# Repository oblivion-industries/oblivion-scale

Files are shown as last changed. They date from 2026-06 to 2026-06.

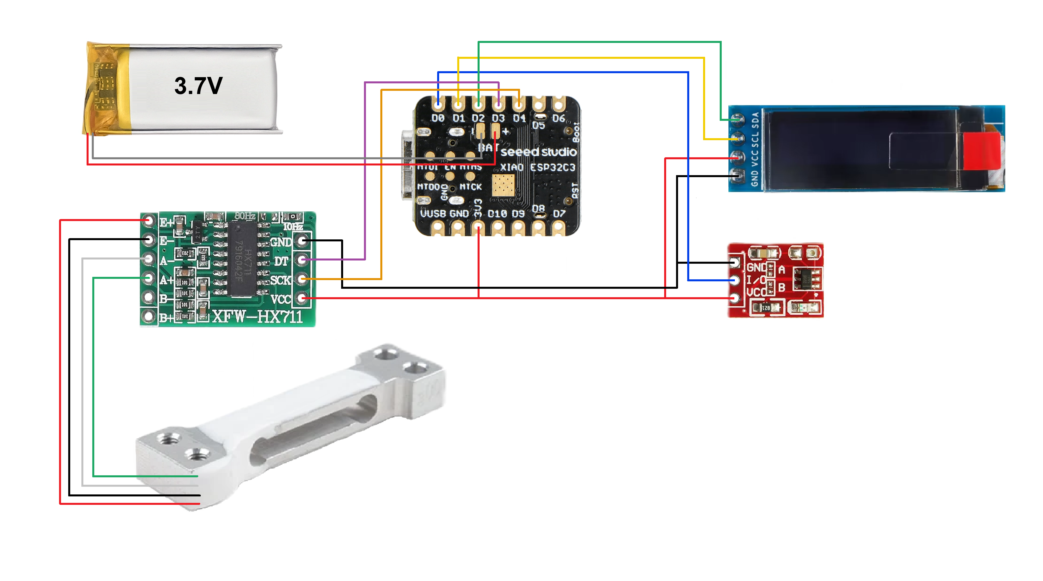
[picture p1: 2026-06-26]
WIRING/v0 wiring diagram.png

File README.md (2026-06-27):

# oblivion-scale

Early **v0 prototype** - open-sourcing the CAD and firmware as a starting point. The rough edges below are exactly where help is welcome.

## Known issues / help wanted

**Body** - v0 is modeled around non-standard parts.
- Re-spec the body around standard, AliExpress-available components.

**Wiring diagram** - v0 is very messy.
- Re-draw the diagram and add a 2-button version.

> [!WARNING]
> Data pins can be changed, but the **wake button** data line **must** be on an **RTC GPIO pin**; otherwise it cannot wake the ESP32 from deep sleep.

**Code** - works, but needs improvement.
- Update for a faster refresh rate.
- Later: add BLE for phone-app compatibility.

## Roadmap

- **Now (v0) - Working prototype:** open-sourcing the body CAD and firmware as a starting point.
- **v1 - Fully open & sourceable:** redesign the body around standard, AliExpress-available parts so anyone can build it cheaply *(bottleneck: load cell)* and improve performance *(bottleneck: ADC)*.
- **v2 - Custom PCB:** a purpose-built board to shrink it further and improve performance.
- **v3 - "Premium" build:** a aluminium and glass version.

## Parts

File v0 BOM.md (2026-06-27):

# Bill of Materials, Open-Source Coffee Scale (v0)

This BOM reflects the v0 prototype. It's a working starting point, not a final parts list. Please read the two notes below before sourcing parts.

## Notes before you buy

**1. Load cell.**
v0 uses a specific, hard-to-source load cell. Selecting a widely-available equivalent is a goal for v1. Changing the load cell will require changes to the v0 CAD.

**2. Part footprints.**
The HX711, TTP223, and OLED ship on breakout boards whose dimensions vary between manufacturers. The v0 CAD is built around the specific boards used in the prototype, so boards of a different size may not fit the enclosure.

## Parts

| # | Part | Qty | Spec / what to get | Notes |
|---|---|-----|---|---|
| 1 | Microcontroller | 1 | Seeed XIAO ESP32-C3 | Built and tested on the C3. The XIAO ESP32-C6 is likely pin-compatible but untested; verify deep-sleep wake before relying on it. |
| 2 | Load cell | 1 | (see Note 1) | v0 used a specific hard-to-source cell. A different cell will require CAD changes. |
| 3 | Load cell ADC | 1 | HX711 24-bit ADC | The board used in the prototype is roughly 24 x 16 mm. Other footprints may not fit. |
| 4 | Touch sensor | 1 | TTP223 capacitive touch | The board used in the prototype is roughly 11 x 15 mm. Other footprints may not fit. |
| 5 | Display | 1 | 0.91" 128x32 OLED, I2C, SSD1306 driver | I2C address typically 0x3C; 4-pin (VCC / GND / SCL / SDA). PCB size varies by maker; the one used in the prototype is roughly 38 x 12 mm. |
| 6 | Battery | 1 | 502030 1S LiPo, 3.7 V | Connector type varies by supplier; source a matching connector to solder to the ESP32 accordingly. Check polarity before connecting: 1S LiPo connector polarity isn't standardized, and reversing it can damage the board. |
| 7 | Threaded inserts | as needed | M3 heat-set inserts | Paired with the M3 bolts below. |
| 8 | Bolts | as needed | M3 bolts | Length depends on final assembly. |
| 9 | Wire | as needed | Hookup wire, gauge to suit | No strict requirement; anything that looks right for low-current signal and power wiring will generally work fine. |

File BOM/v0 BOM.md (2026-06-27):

# Bill of Materials, Open-Source Coffee Scale (v0)

This BOM reflects the v0 prototype. It's a working starting point, not a final parts list. Please read the two notes below before sourcing parts.

## Notes before you buy

**1. Load cell.**
v0 uses a specific, hard-to-source load cell. Selecting a widely-available equivalent is a goal for v1. Changing the load cell will require changes to the v0 CAD.

**2. Part footprints.**
The HX711, TTP223, and OLED ship on breakout boards whose dimensions vary between manufacturers. The v0 CAD is built around the specific boards used in the prototype, and are friction fit, so boards of a different size may not fit the enclosure.

## Parts

| # | Part | Qty | Spec / what to get | Notes |
|---|---|-----|---|---|
| 1 | Microcontroller | 1 | Seeed XIAO ESP32-C3 | Built and tested on the C3. The XIAO ESP32-C6 is likely pin-compatible but untested; verify deep-sleep wake before relying on it. |
| 2 | Load cell | 1 | (see Note 1) | v0 used a specific hard-to-source cell. A different cell will require CAD changes. |
| 3 | Load cell ADC | 1 | HX711 24-bit ADC | The board used in the prototype is roughly 24 x 16 mm. |
| 4 | Touch sensor | 1 | TTP223 capacitive touch sensor | The board used in the prototype is roughly 11 x 15 mm. |
| 5 | Display | 1 | 0.91" 128x32 OLED, I2C, SSD1306 driver | I2C address typically 0x3C; 4-pin (VCC / GND / SCL / SDA). PCB size varies by maker; the one used in the prototype is roughly 38 x 12 mm. |
| 6 | Battery | 1 | 502030 3.7 V LiPo | Connector type varies by supplier; source a matching connector to solder to the ESP32 accordingly. Check polarity before connecting: reversing it can damage the board. |
| 7 | Threaded inserts | as needed | M3 heat-set inserts | Paired with the M3 bolts below. |
| 8 | Bolts | as needed | M3 bolts | Length depends on final assembly. |
| 9 | Wire | as needed | Hookup wire, gauge to suit | No strict requirement; anything that looks right for low-current signal and power wiring will generally work fine. |

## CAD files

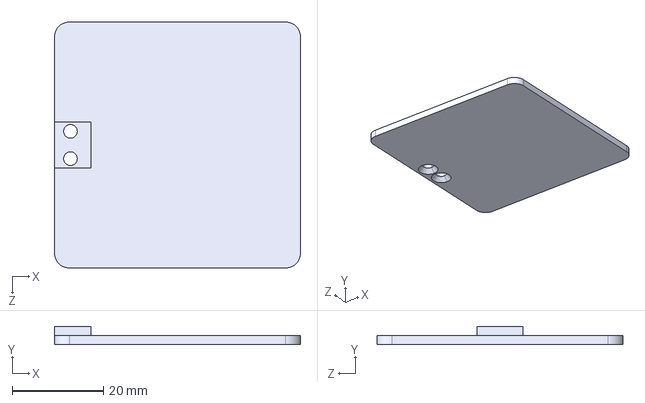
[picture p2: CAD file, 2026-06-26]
CAD/v0 body (base).STEP
54.0 x 4.00 x 54.0 mm

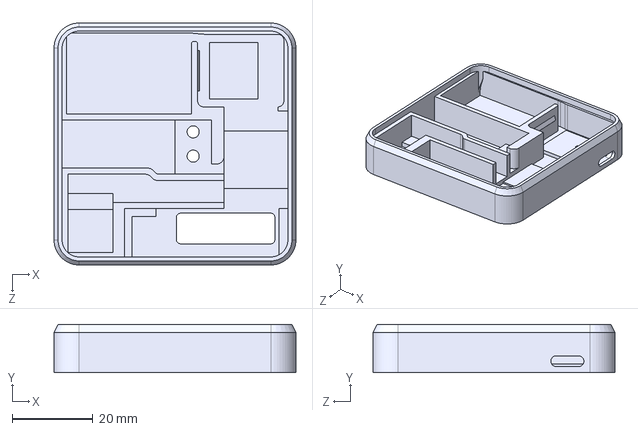
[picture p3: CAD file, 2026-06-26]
CAD/v0 body (top).STEP
60.0 x 12.0 x 60.0 mm

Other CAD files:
CAD/v0 body (base).STL
CAD/v0 body (top).STL

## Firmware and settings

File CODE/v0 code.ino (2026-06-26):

#include <Wire.h>
#include <Adafruit_GFX.h>
#include <Adafruit_SSD1306.h>
#include "HX711.h"
#include "esp_sleep.h"
#include "driver/gpio.h"

#define OLED_SDA 4
#define OLED_SCL 3

#define HX_DT   5
#define HX_SCK  6

#define TOUCH_PIN 2

Adafruit_SSD1306 display(128, 32, &Wire, -1);
HX711 scale;

float calibration_factor = 1988; // adjust later

bool wasTouch = false;
uint32_t touchStart = 0;
bool longHandled = false;

bool timerRunning = false;
bool brewStarted = false;
uint32_t brewStart = 0;
uint32_t timerElapsed = 0;

void oledMsg(const char* line1, const char* line2 = "", const char* line3 = "", const char* line4 = "") {
  display.clearDisplay();
  display.setTextSize(1);
  display.setTextColor(SSD1306_WHITE);
  display.setCursor(0, 0);
  display.println(line1);
  if (line2[0]) display.println(line2);
  if (line3[0]) display.println(line3);
  if (line4[0]) display.println(line4);
  display.display();
}

void goDeepSleep() {
  oledMsg("GOING TO SLEEP", "tap to wake", "                  zzz", "             (-.-)");

  scale.power_down();
  delay(30);

  // avoid instant wake if finger still touching
  while (digitalRead(TOUCH_PIN) == HIGH) delay(10);

  display.ssd1306_command(SSD1306_DISPLAYOFF);
  delay(30);

  oledMsg("COFFEE TIME !!!");

  // deep-sleep wake on GPIO
  esp_deep_sleep_enable_gpio_wakeup(1ULL << TOUCH_PIN, ESP_GPIO_WAKEUP_GPIO_HIGH);

  esp_deep_sleep_start();
}

void setup() {
  Serial.begin(115200);

  // pull-down for stability
  pinMode(TOUCH_PIN, INPUT_PULLDOWN);

  Wire.begin(OLED_SDA, OLED_SCL);
  display.begin(SSD1306_SWITCHCAPVCC, 0x3C);

  pinMode(HX_SCK, OUTPUT);
  digitalWrite(HX_SCK, LOW);

  scale.begin(HX_DT, HX_SCK);
  scale.set_gain(128);
  delay(200);

  scale.set_scale(calibration_factor);
  scale.tare();

  oledMsg("COFFEE TIME!!!", "tap when ready");

  while (digitalRead(TOUCH_PIN) == LOW) delay(10);
}

void loop() {
  bool touch = (digitalRead(TOUCH_PIN) == HIGH);

  // touch edge -> start timing
  if (touch && !wasTouch) {
    touchStart = millis();
    longHandled = false;
  }

  // long hold -> deep sleep
  if (touch && !longHandled && (millis() - touchStart >= 2500)) {
    longHandled = true;
    goDeepSleep();
    return;
  }

  // release edge:
  if (!touch && wasTouch) {
    uint32_t dur = millis() - touchStart;
    if (dur < 2500) {
      // stop timer
      if (timerRunning) {
        timerRunning = false;
        timerElapsed = millis() - brewStart;
      }
      // tare only if timer NOT running
      else {
        scale.tare();
        brewStarted = false;
        timerElapsed = 0;
      }
    }
  }

  wasTouch = touch;

  // Read weight
  float w = scale.get_units(5);

  // auto start timer
  if (!brewStarted && w > 0.1) {
  brewStarted = true;
  timerRunning = true;
  brewStart = millis();
}

  // currenmt time
  uint32_t currentTime = timerElapsed;

  if (timerRunning) {
    currentTime = millis() - brewStart;
  }

  uint32_t seconds = currentTime / 1000;
  uint32_t minutes = seconds / 60;
  seconds = seconds % 60;

  // display
  display.clearDisplay();

  display.setTextSize(1);
  display.setCursor(0, 0);
  display.print("Weight:");

  display.setCursor(80,0);
  display.print("Time");

  display.setTextSize(2);
  display.setCursor(0, 12);
  display.print(w, 2);
  display.print("g");

  display.setCursor(80,12);
  display.print(seconds);
  display.print("s");

  display.display();
  delay(100);
}

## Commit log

2026-06-26 v0 body upload
    [v0 body (base).STEP, v0 body (base).STL, v0 body (top).STEP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]
2026-06-26 v0 wiring diagram
    This is the current wiring for the prototype
2026-06-26 wiring notes
2026-06-26 License for cad files
2026-06-26 Rename v0 body (base).STEP to CAD/v0 body (base).STEP
    [v0 body (base).STEP]
2026-06-26 Rename v0 body (base).STL to CAD/v0 body (base).STL
    [v0 body (base).STL]
2026-06-26 Rename v0 body (top).STEP to CAD/v0 body (top).STEP
    [v0 body (top).STEP]
2026-06-26 Rename v0 body (top).STL to CAD/v0 body (top).STL
    [v0 body (top).STL]
2026-06-26 Rename v0 wiring diagram.png to WIRING/v0 wiring diagram.png
2026-06-27 v0 BOM
2026-06-27 Update and rename v0 BOM.md to BOM/v0 BOM.md
2026-06-27 Clarify touch sensor description in BOM
2026-06-27 Clarified battery and load cell explanations
2026-06-27 BOM created, readme ajusted
    Removed BOM creation note from README.
